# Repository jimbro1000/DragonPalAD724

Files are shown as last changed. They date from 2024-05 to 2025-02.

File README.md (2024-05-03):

# Dragon PAL Video Board Concept 3 #
This repository contains the design for
a video board for the Dragon 32 rev 3 
evolution main board

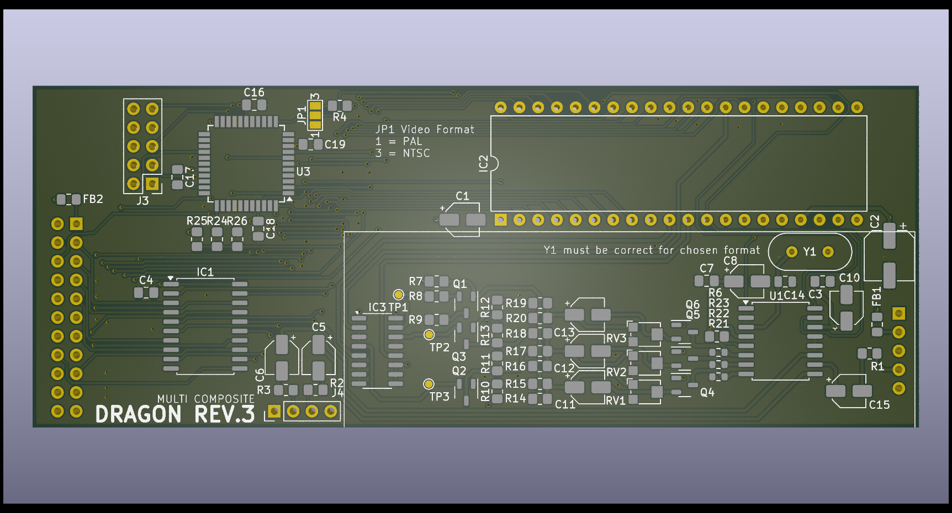
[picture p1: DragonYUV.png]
Dragon 32 revision 3 PAL video pcb render


## YUV -> RGB ##
The design here converts the YUV output 
of the VDG chip into RGB in order to
drive an Analog Devices AD724JR 
signal modulator

Translation is performed per channel to calculate
the relative R-Y and B-Y values that can be 
combined with an inverted Y signal to produce
RGB. Each output channel can then be fine tuned for
strength independently.

The resulting RGB signals are fed to the
AD724 which provides signal modulation and
synthesizes the sync signals. The original
sync in the source luma signal is ignored.

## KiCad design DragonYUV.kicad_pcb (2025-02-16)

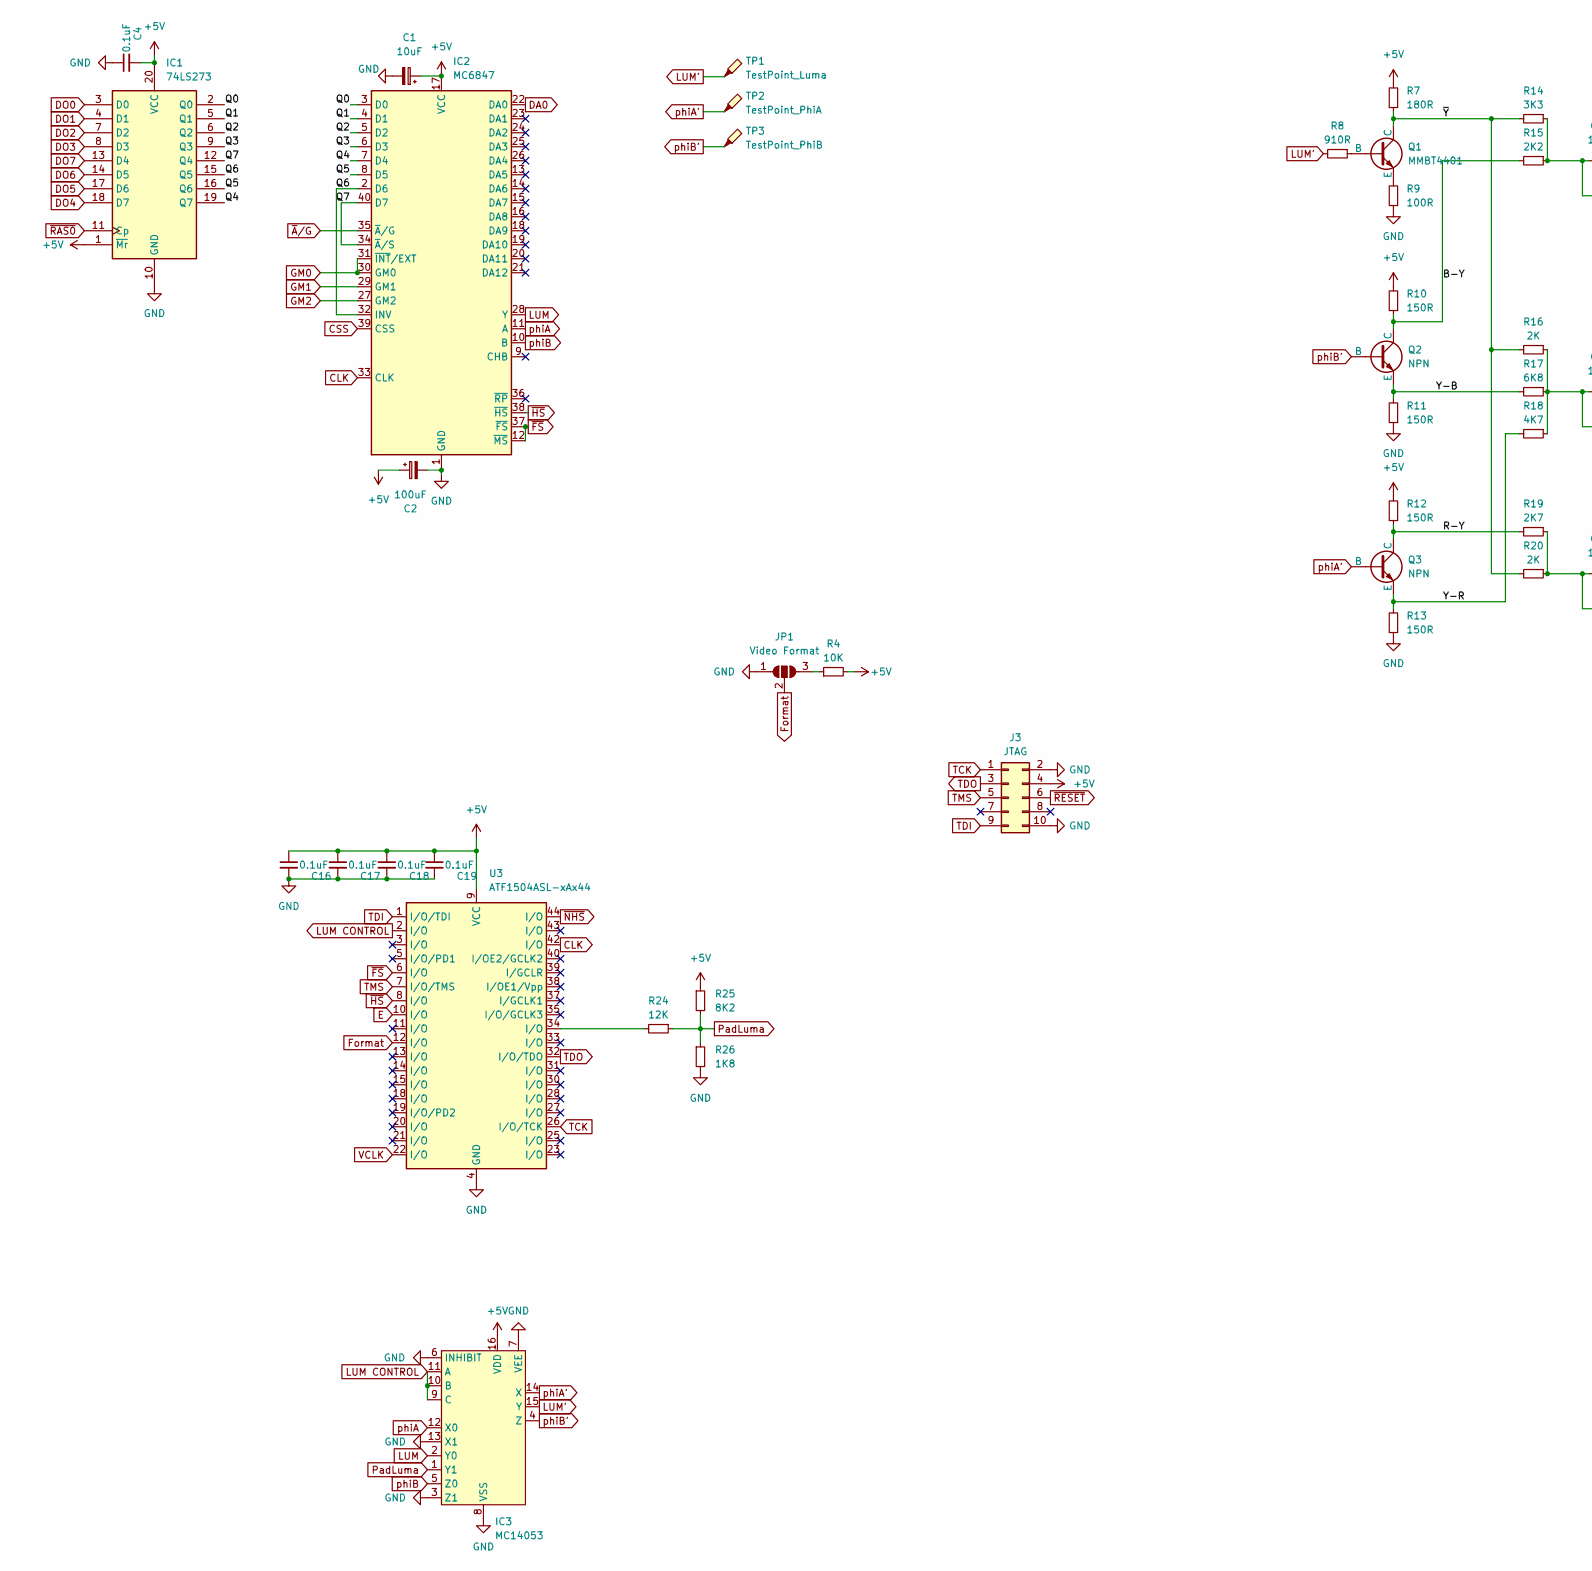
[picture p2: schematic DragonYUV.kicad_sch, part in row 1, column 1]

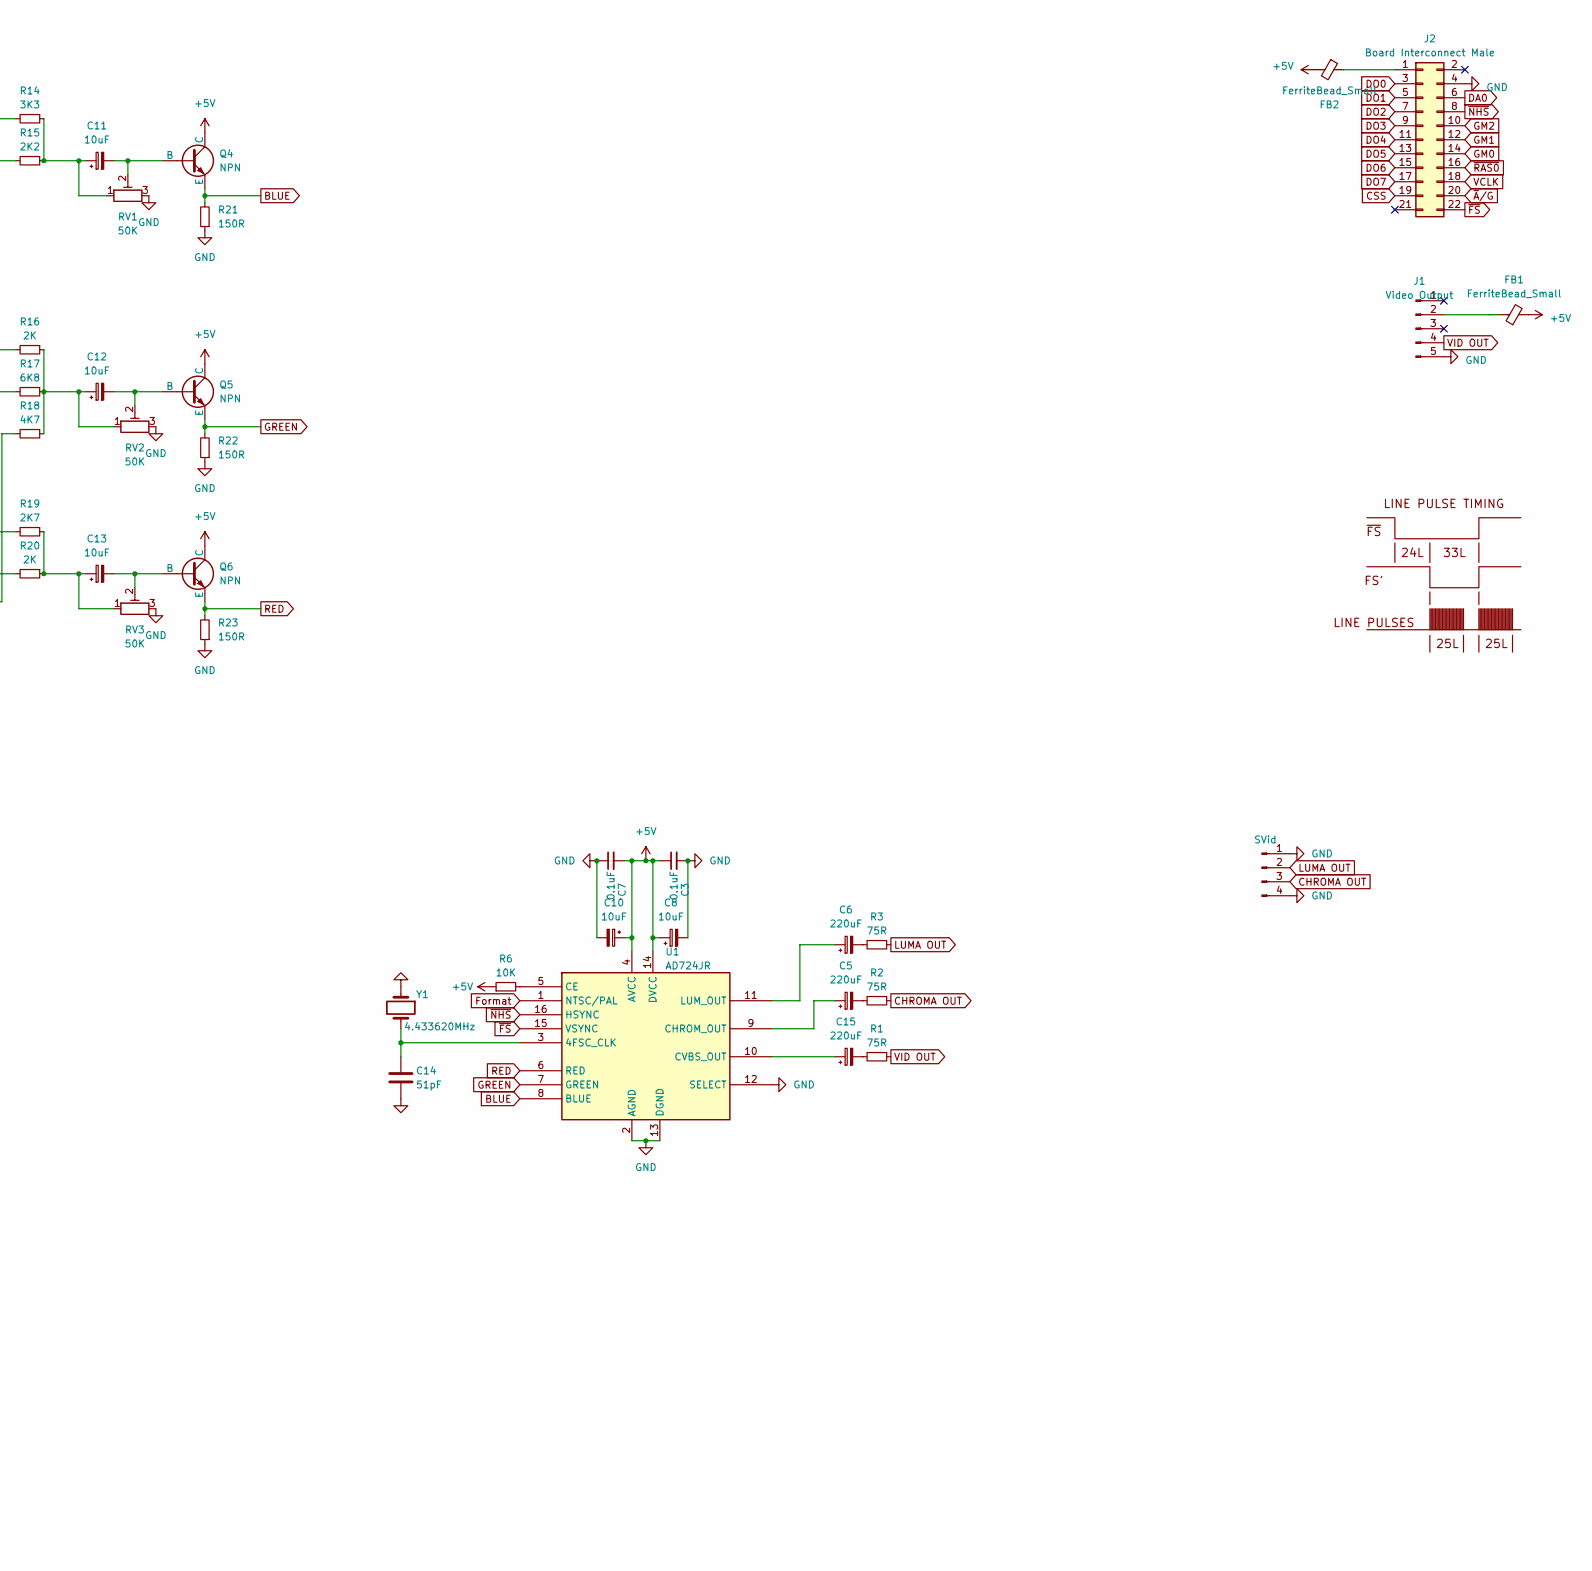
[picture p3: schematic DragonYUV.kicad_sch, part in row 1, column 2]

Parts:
C1, C8, C10, C11, C12, C13: 10uF; CP_Elec_4x5.4; DigiKey 732-6401-1-ND
C2: 100uF; CP_Elec_6.3x5.8; DigiKey 732-8254-1-ND
C3, C4, C7, C16, C17, C18, C19: 0.1uF; C_0805_2012Metric_Pad1.18x1.45mm_HandSolder; DigiKey 399-C0805C104M5RAC7800CT-ND
C5, C6, C15: 220uF; CP_Elec_4x5.4; DigiKey 732-6401-1-ND
C14: 51pF; C_0805_2012Metric; DigiKey 399-C0805C510F1GAC7800CT-ND
FB1, FB2: FerriteBead_Small; L_0805_2012Metric_Pad1.15x1.40mm_HandSolder
IC1: 74LS273; SOIC-20W_7.5x12.8mm_P1.27mm; DigiKey 296-3682-1-ND
IC2: MC6847; DIP-40_W15.24mm
IC3: MC14053; SOIC-16_3.9x9.9mm_P1.27mm; DigiKey 296-2059-ND
J1: Video Output; PinHeader_1x05_P2.54mm_Vertical
J2: Board Interconnect Male; PinHeader_2x11_P2.54mm_Vertical
J3: JTAG; PinHeader_2x05_P2.54mm_Vertical
J4: SVid; PinHeader_1x04_P2.54mm_Vertical
JP1: Video Format; SolderJumper-3_P1.3mm_Open_Pad1.0x1.5mm_NumberLabels
Q1: MMBT4401; SOT-23-3
Q2, Q3, Q4, Q5, Q6: NPN; SOT-23-3
R1, R2, R3: 75R; R_0805_2012Metric_Pad1.20x1.40mm_HandSolder; DigiKey CF14JT6K80CT-ND
R4, R6: 10K; R_0805_2012Metric_Pad1.20x1.40mm_HandSolder; DigiKey CF14JT6K80CT-ND
R7: 180R; R_0805_2012Metric_Pad1.20x1.40mm_HandSolder; DigiKey CF14JT6K80CT-ND
R8: 910R; R_0805_2012Metric_Pad1.20x1.40mm_HandSolder; DigiKey CF14JT6K80CT-ND
R9: 100R; R_0805_2012Metric_Pad1.20x1.40mm_HandSolder; DigiKey CF14JT6K80CT-ND
R10, R11, R12, R13: 150R; R_0805_2012Metric_Pad1.20x1.40mm_HandSolder; DigiKey CF14JT6K80CT-ND
R14: 3K3; R_0805_2012Metric_Pad1.20x1.40mm_HandSolder; DigiKey CF14JT6K80CT-ND
R15: 2K2; R_0805_2012Metric_Pad1.20x1.40mm_HandSolder; DigiKey CF14JT6K80CT-ND
R16, R20: 2K; R_0805_2012Metric_Pad1.20x1.40mm_HandSolder; DigiKey CF14JT6K80CT-ND
R17: 6K8; R_0805_2012Metric_Pad1.20x1.40mm_HandSolder; DigiKey CF14JT6K80CT-ND
R18: 4K7; R_0805_2012Metric_Pad1.20x1.40mm_HandSolder; DigiKey CF14JT6K80CT-ND
R19: 2K7; R_0805_2012Metric_Pad1.20x1.40mm_HandSolder; DigiKey CF14JT6K80CT-ND
R21, R22, R23: 150R; R_0603_1608Metric; DigiKey CF14JT6K80CT-ND
R24: 12K; R_0805_2012Metric_Pad1.20x1.40mm_HandSolder; DigiKey CF14JT6K80CT-ND
R25: 8K2; R_0805_2012Metric_Pad1.20x1.40mm_HandSolder; DigiKey CF14JT6K80CT-ND
R26: 1K8; R_0805_2012Metric_Pad1.20x1.40mm_HandSolder; DigiKey CF14JT6K80CT-ND
RV1, RV2, RV3: 50K; Potentiometer_Bourns_TC33X_Vertical; DigiKey TC42X-2-503ECT-ND
TP1: TestPoint_Luma; TestPoint_Pad_D1.0mm
TP2: TestPoint_PhiA; TestPoint_Pad_D1.0mm
TP3: TestPoint_PhiB; TestPoint_Pad_D1.0mm
U1: AD724JR; SOIC-16W_7.5x10.3mm_P1.27mm
U3: ATF1504ASL-xAx44; TQFP-44_10x10mm_P0.8mm; DigiKey ATF1504ASL-25AU44-ND
Y1: 4.433620MHz; Crystal_HC18-U_Vertical; DigiKey XC1263CT-ND
Z1: LINE_PULSE_DIAGRAM

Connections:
+5V: C1.1, C2.1, C3.1, C4.2, C7.2, C8.1, C10.1, C16.1, C17.1, C18.1, C19.1, FB1.2, FB2.2, IC1.1 (~Mr), IC1.20 (VCC), IC2.17 (VCC), IC3.16 (VDD), J3.4, Q4.1 (C), Q5.1 (C), Q6.1 (C), R4.2, R6.1, R7.2, R10.2, R12.2, R25.1, U1.4 (AVCC), U1.14 (DVCC), U3.9 (VCC), U3.17 (VCC), U3.29 (VCC), U3.41 (VCC)
/B-Y: Q2.1 (C), R10.1, R15.2
/Q0: IC1.2 (Q0), IC2.3 (D0)
/Q1: IC1.5 (Q1), IC2.4 (D1)
/Q2: IC1.6 (Q2), IC2.5 (D2)
/Q3: IC1.9 (Q3), IC2.6 (D3)
/Q4: IC1.19 (Q7), IC2.7 (D4)
/Q5: IC1.16 (Q6), IC2.8 (D5)
/Q6: IC1.15 (Q5), IC2.2 (D6), IC2.32 (INV)
/Q7: IC1.12 (Q4), IC2.34 (~A/S), IC2.40 (D7)
/R-Y: Q3.1 (C), R12.1, R19.2
/Y-B: Q2.3 (E), R11.2, R17.2
/Y-R: Q3.3 (E), R13.2, R18.2
/~Y: Q1.1 (C), R7.1, R14.2, R16.2, R20.2
BLUE: Q4.3 (E), R21.2, U1.8 (BLUE)
CHROMA OUT: J4.3, R2.1
CLK: IC2.33 (CLK), U3.42 (I/O)
CSS: IC2.39 (CSS), J2.19
DA0: IC2.22 (DA0), J2.6
DO0: IC1.3 (D0), J2.3
DO1: IC1.4 (D1), J2.5
DO2: IC1.7 (D2), J2.7
DO3: IC1.8 (D3), J2.9
DO4: IC1.18 (D7), J2.11
DO5: IC1.17 (D6), J2.13
DO6: IC1.14 (D5), J2.15
DO7: IC1.13 (D4), J2.17
E: U3.10 (I/O)
Format: JP1.2 (C), U1.1 (NTSC/PAL), U3.12 (I/O)
GM0: IC2.30 (GM0), IC2.31 (~INT/EXT), J2.14
GM1: IC2.29 (GM1), J2.12
GM2: IC2.27 (GM2), J2.10
GND: C1.2, C2.2, C3.2, C4.1, C7.1, C8.2, C10.2, C14.2, C16.2, C17.2, C18.2, C19.2, IC1.10 (GND), IC2.1 (GND), IC3.3 (Z1), IC3.6 (INHIBIT), IC3.7 (VEE), IC3.8 (VSS), IC3.13 (X1), J1.5, J2.4, J3.2, J3.10, J4.1, J4.4, JP1.1 (A), R9.1, R11.1, R13.1, R21.1, R22.1, R23.1, R26.2, RV1.3, RV2.3, RV3.3, U1.2 (AGND), U1.12 (SELECT), U1.13 (DGND), U3.4 (GND), U3.16 (GND), U3.24 (GND), U3.36 (GND), Y1.1
GREEN: Q5.3 (E), R22.2, U1.7 (GREEN)
LUM: IC2.28 (Y), IC3.2 (Y0)
LUM CONTROL: IC3.9 (C), IC3.10 (B), IC3.11 (A), U3.2 (I/O)
LUM': IC3.15 (Y), R8.2, TP1.1
LUMA OUT: J4.2, R3.1
unnamed: C5.2, R2.2
unnamed: C6.2, R3.2
unnamed: C11.1, R14.1, R15.1, RV1.1
unnamed: C12.1, R16.1, R17.1, R18.1, RV2.1
unnamed: C13.1, R19.1, R20.1, RV3.1
unnamed: C15.2, R1.2
unnamed: FB1.1, J1.2
unnamed: FB2.1, J2.1
unnamed: JP1.3 (B), R4.1
unnamed: Q1.2 (B), R8.1
unnamed: Q1.3 (E), R9.2
unnamed: C11.2, Q4.2 (B), RV1.2
unnamed: C12.2, Q5.2 (B), RV2.2
unnamed: C13.2, Q6.2 (B), RV3.2
unnamed: R24.2, U3.34 (I/O)
unnamed: C14.1, U1.3 (4FSC_CLK), Y1.2
unnamed: R6.2, U1.5 (CE)
unnamed: C5.1, U1.9 (CHROM_OUT)
unnamed: C15.1, U1.10 (CVBS_OUT)
unnamed: C6.1, U1.11 (LUM_OUT)
PadLuma: IC3.1 (Y1), R24.1, R25.2, R26.1
RED: Q6.3 (E), R23.2, U1.6 (RED)
TCK: J3.1, U3.26 (I/O/TCK)
TDI: J3.9, U3.1 (I/O/TDI)
TDO: J3.3, U3.32 (I/O/TDO)
TMS: J3.5, U3.7 (I/O/TMS)
VCLK: J2.18, U3.22 (I/O)
VID OUT: J1.4, R1.1
phiA: IC2.11 (A), IC3.12 (X0)
phiA': IC3.14 (X), Q3.2 (B), TP2.1
phiB: IC2.10 (B), IC3.5 (Z0)
phiB': IC3.4 (Z), Q2.2 (B), TP3.1
~A/G: IC2.35 (~A/G), J2.20
~FS: IC2.12 (~MS), IC2.37 (~FS), J2.22, U1.15 (VSYNC), U3.6 (I/O)
~HS: IC2.38 (~HS), U3.8 (I/O)
~NHS: J2.8, U1.16 (HSYNC), U3.44 (I/O)
~RAS0: IC1.11 (Cp), J2.16
~RESET: J3.6

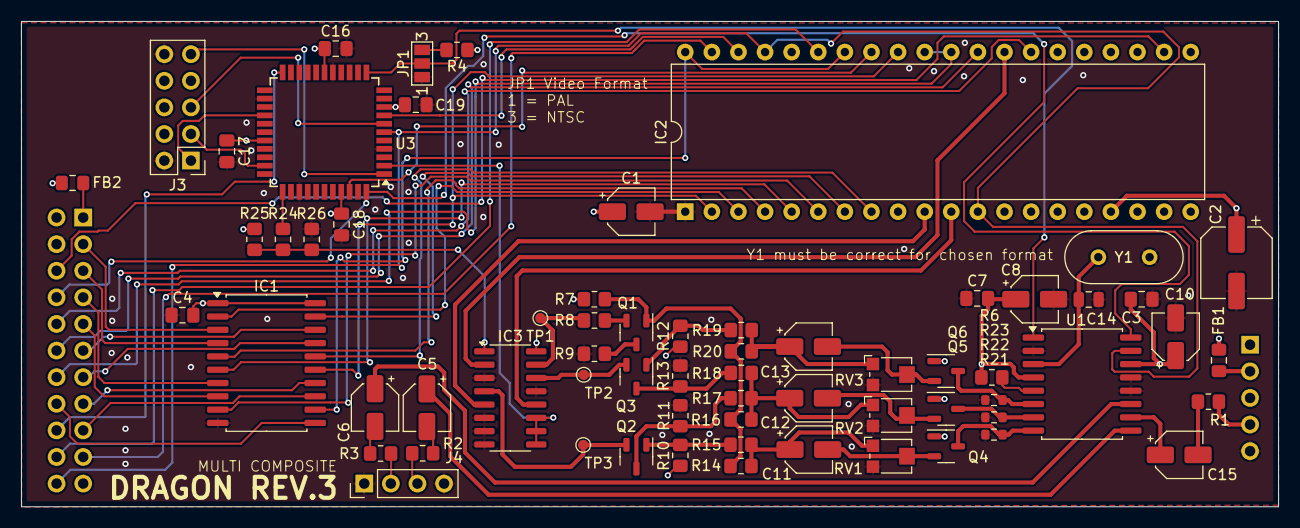
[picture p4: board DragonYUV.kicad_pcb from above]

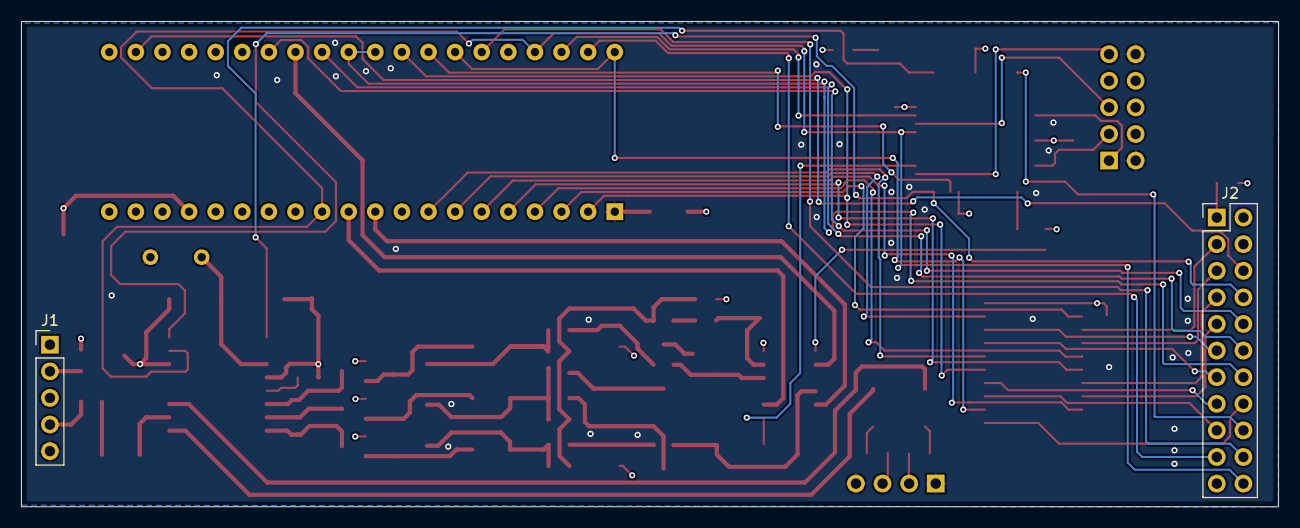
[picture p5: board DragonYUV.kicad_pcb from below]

Board: 4 copper layers, 120.0 x 46.3 mm, 68 parts (2 on the bottom side), 74 nets.

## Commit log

2024-05-02 tidy up
    [DragonYUV.kicad_pcb, DragonYUV.kicad_sch]
2024-05-03 update pcb file
    [DragonYUV.kicad_pcb]
2024-05-03 reworked layout
    [DragonYUV.kicad_pcb, DragonYUV.kicad_sch]
2024-05-03 Clean up board Improve trace quality
    [DragonYUV.kicad_pcb, DragonYUV.kicad_sch]
2024-06-12 bolster video output routing
    [DragonYUV.kicad_pcb]
2024-06-12 convert to cpld
    [DragonYUV.kicad_pcb, DragonYUV.kicad_sch]
2025-02-11 update design to provide ntsc and pal switching
    [DragonYUV.kicad_pcb, DragonYUV.kicad_sch]
2025-02-12 rework schematics for demux of video
    [DragonYUV.kicad_pcb, DragonYUV.kicad_sch]
2025-02-16 compose verilog
    [DragonYUV.kicad_pcb, DragonYUV.kicad_sch]
